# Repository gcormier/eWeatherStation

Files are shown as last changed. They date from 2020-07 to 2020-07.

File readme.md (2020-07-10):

# eWeatherstation
eWeatherstation is a simple weather station with a twist

1. It has an onboard temperature/humidity sensor
2. It can receive RF signals from nearby sensors such as the AcuRite 06002RM to display the actual outdoor temperature

It is powered by an ESP32, and has support for a LiPo battery and charging circuitry via Micro USB.

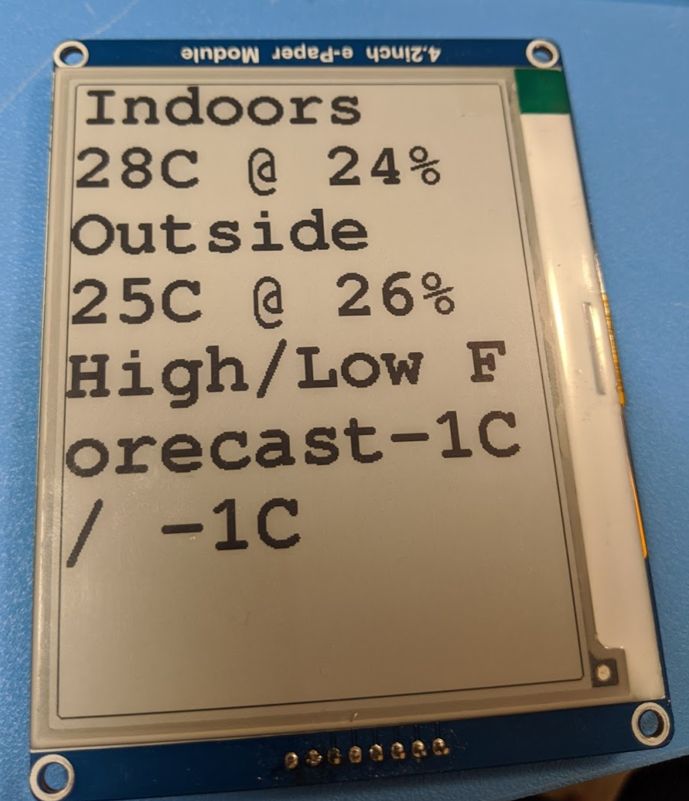
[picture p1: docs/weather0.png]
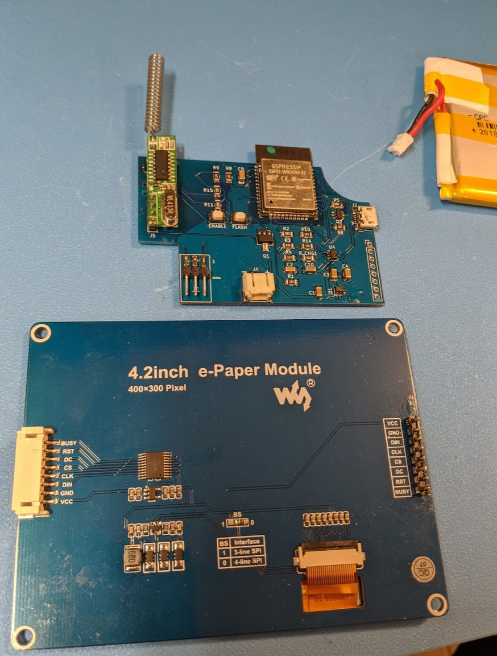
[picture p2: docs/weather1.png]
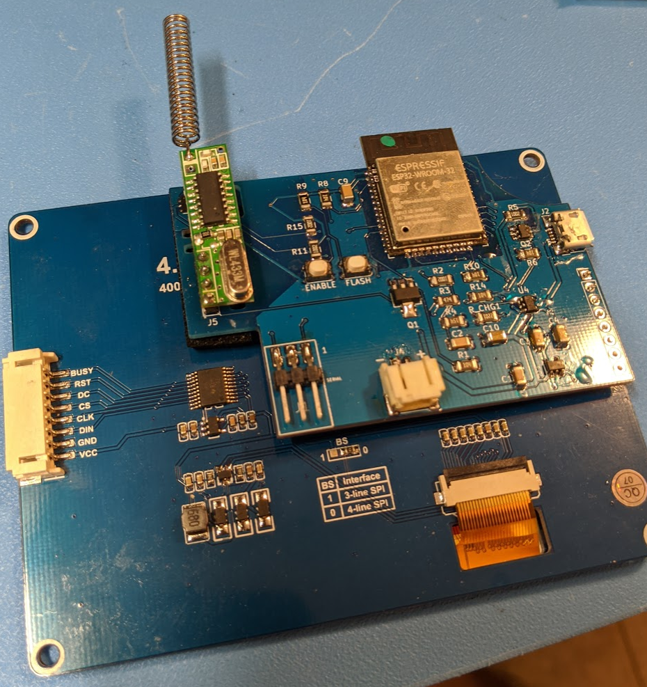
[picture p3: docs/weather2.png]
  

## Todo list
- [ ] 3D-Printed Housing
- [ ] Make UI look good
- [ ] Hardware revision to use esp32buddy programmer

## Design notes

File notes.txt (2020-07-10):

- Target 3v3, so 1S lipo
- Integrated charger, mcu detects low voltage
- No protection for battery+programming at the same time

https://download.mikroe.com/documents/add-on-boards/click/eink/eink-click-schematic-v101.pdf

- ESP32 in deep sleep - 2.8uA
- Around 45mA when in use (no wifi)
- takes about 140ms to wake up from deep sleep with an interrupt

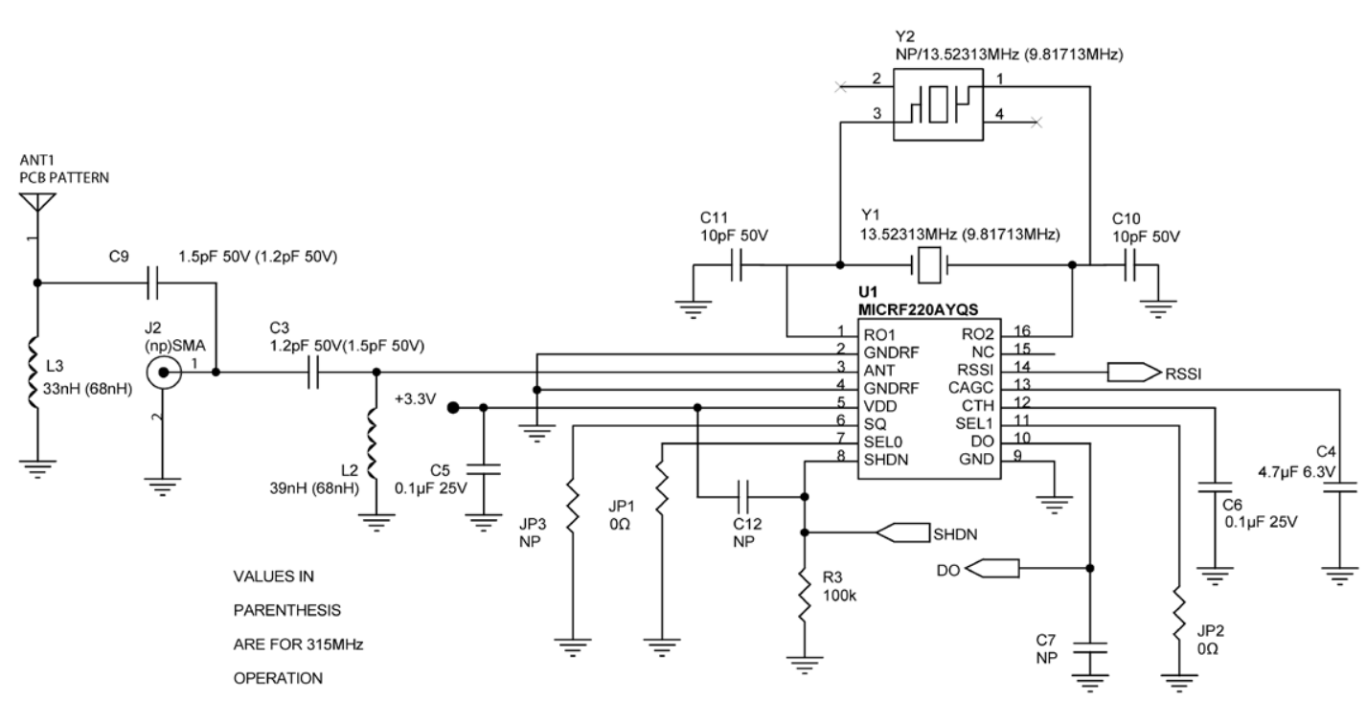
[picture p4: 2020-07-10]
pcb/MICRF220 Reference Schematic.png

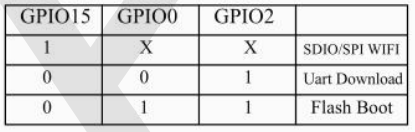
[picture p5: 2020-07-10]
pcb/8266 boot.png

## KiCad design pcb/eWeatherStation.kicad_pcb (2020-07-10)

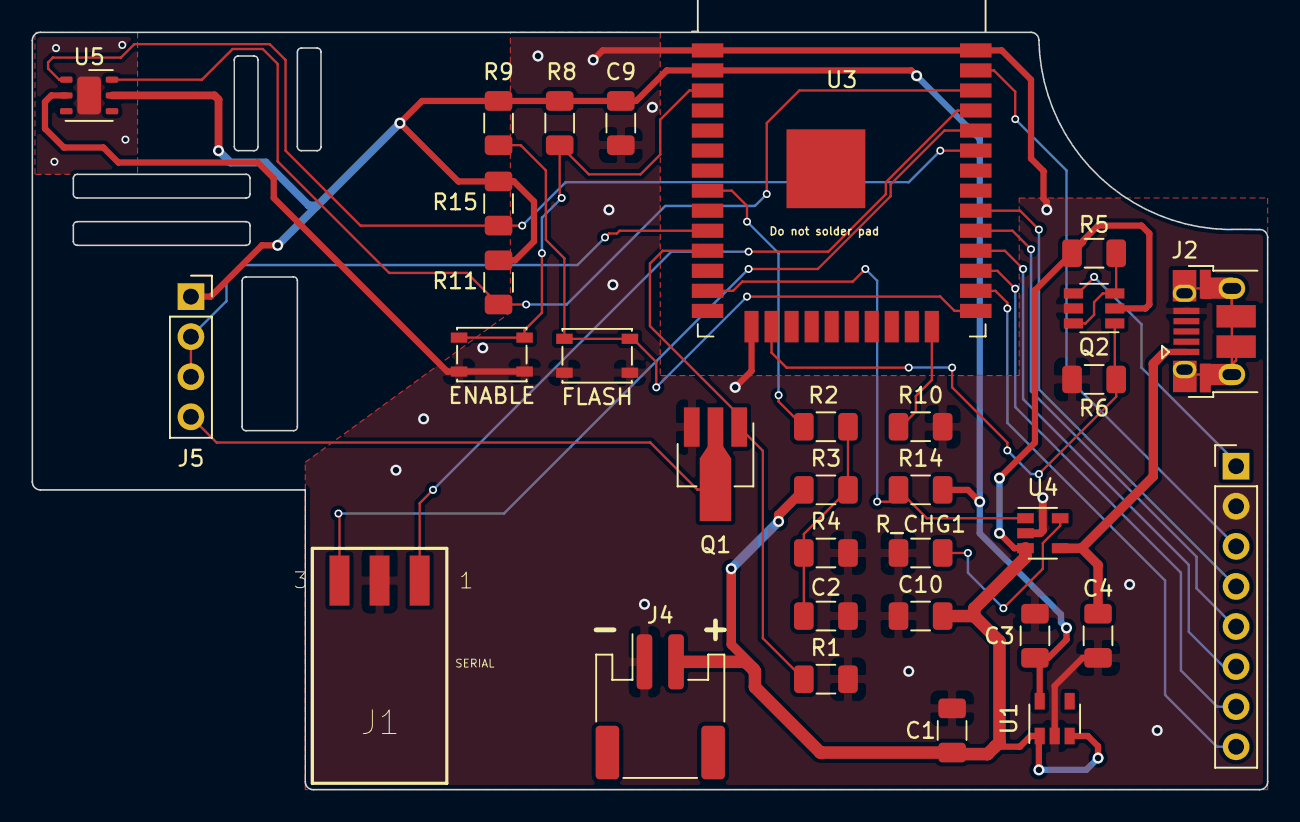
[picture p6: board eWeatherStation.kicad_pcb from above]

Board: 2 copper layers, 78.3 x 48.0 mm, 32 parts (0 on the bottom side), 27 nets.

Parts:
C1, C3: 1uF; C_1206_3216Metric
C2: 0.1uF; C_1206_3216Metric
C4, C10: 4.7uF; C_1206_3216Metric
C9: 10uF; C_1206_3216Metric
J1: SERIAL; SAMTEC-TSM-103-01-X-SH
J2: USB_B_Micro; USB_Micro-B_Amphenol_10103594-0001LF_Horizontal
J3: CASTELLATION; PinHeader_1x08_P2.54mm_Vertical
J4: 1S_BATTERY; JST_PH_S2B-PH-SM4-TB_1x02-1MP_P2.00mm_Horizontal
J5: RECEIVER; PinSocket_1x04_P2.54mm_Vertical
Q1: ZXMN3A01Z; SOT-89-3_Handsoldering
Q2: DMC2053UVT; TSOT-23-6
R1, R6, R8, R9, R10, R14: 100k; R_1206_3216Metric
R2, R5, R11, R15: 10k; R_1206_3216Metric
R3: 470k; R_1206_3216Metric
R4: 150k; R_1206_3216Metric
R_CHG1: 2k2; R_1206_3216Metric
SW1: ENABLE; SW_SPST_PTS810
SW2: FLASH; SW_SPST_PTS810
U1: TLV75533PDBV; SOT-23-5
U3: ESP32-WROOM-32D; ESP32-WROOM-32
U4: MCP73831-2-OT; SOT-23-5
U5: Si7021-A20; DFN-6-1EP_3x3mm_P1mm_EP1.5x2.4mm

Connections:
+3V3: C3.1, C9.2, J5.1, R8.2, R9.2, R11.1, R14.2, R15.1, U1.5, U3.2, U5.5
+BATT: C1.2, C10.2, J4.2, Q2.2, R3.2, R5.1, U1.1, U1.3, U4.3
/ADC_BATT: R2.2, U3.8
/CHG_STAT: R14.1, U3.13, U4.1
/DISPLAY_ENABLE: Q2.1, R6.1, U3.16
/RADIO: J5.2, J5.3, U3.10
/RADIO_ENABLE: Q1.1, R1.1, U3.11
/RXD: J1.3, U3.34
/SCL: R11.2, U3.36, U5.6
/SDA: R15.2, U3.33, U5.1
/TXD: J1.1, U3.35
/eBUSY: J3.8, U3.26
/eCLK: J3.4, U3.30
/eCS: J3.5, U3.29
/eDC: J3.6, U3.28
/eDIN: J3.3, U3.37
/eRST: J3.7, U3.27
GND: C1.1, C2.2, C3.2, C4.1, C9.1, C10.1, J1.2, J2.5, J3.2, J4.1, Q1.3, Q2.5, R1.2, R4.2, R6.2, R10.2, R_CHG1.1, SW1.2, SW2.2, U1.2, U3.1, U3.15, U3.38, U4.2, U5.2
unnamed: C2.1, R2.1, R3.1, R4.1
unnamed: J3.1, Q2.4
unnamed: J5.4, Q1.2
unnamed: Q2.3, Q2.6, R5.2
unnamed: R8.1, SW1.1, U3.3
unnamed: R9.1, SW2.1, U3.25
unnamed: R10.1, U3.24
unnamed: R_CHG1.2, U4.5
VBUS: C4.2, J2.1, U4.4

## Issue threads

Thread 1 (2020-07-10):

Help finishing software

gcormier, 2020-07-10:
Need some motivation to drive this home. Is anyone willing to finish off the code to look a bit better?

- [ ] Horizontal aspect ratio
- [ ] Pull weather forecast
- [ ] Make GUI look good

I'm willing to send off the hardware to get this done. I'd send a fully assembled PCB. You would need your own Waveshare e-ink display, Acurite sensor, and the tools and knowledge to program it. (It'd be great to have some sort of history/indication of your ability to do so)

(Battery is also up to you, but it can also be run off USB)

rruggiero, 2020-07-17:
Hi,

I am willing to help you with the design and prototyping of any 3d printed case you care thinking about.  Is it intended for indoor or out door use, or maybe both ?

As for the UI, what did you have in mind for that ?

Cheers,

Rick (Queensland, Australia)

gcormier, 2020-07-17:
Awesome! I think the case could be very simple, it merely needs to provide access to the USB port for charging. It is for interior use.

GUI also simple is fine. If it's just showing the various temperatures, a simple breakdown. If it's showing weather forecast, looks like there are already many many weatherstations that do that, so it could be just reworking those to be a bit smaller. https://learn.adafruit.com/epaper-weather-station

Thinking more about it,  I already have many devices that show me weather forecasts... Ecobee, phones, google speakers.. I've always cared more about what it actually is outside my house and not at the airport :)

In which case, the UI could simply be nicely formatted indoor and outdoor temps. Perhaps, depending on the season, the forecasted extremes (low/high) for the day? I am quite open to suggestion.

gcormier, 2020-07-17:
Oh wow, this one looks like it already has some space in the bottom for an internal sensor - and room to the right easily for an external one.

https://github.com/andrei7c4/weatherdisplay

gcormier, 2020-07-29:
Hey Rick, were you still interested?

rruggiero, 2020-07-30:
H Greg,

I think you were looking for someone to look at the interface and case, is the correct.  Well, I would like to offer any assistance you may need on this project.

Kindest regards,

Rick Ruggiero

e: rick.ruggiero@gmail.com <mailto:rick.ruggiero@gmail.com>

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

gcormier, 2020-07-30:
Yup that sounds good! If you want to send me an email with your address I
can send you the board in a week or two to start playing. As mentioned
you'll need your own e-ink display and programming tools.

On Wed, Jul 29, 2020 at 11:55 PM Rick Ruggiero <notifications@github.com>
wrote:

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

Closed 2023-06-22.

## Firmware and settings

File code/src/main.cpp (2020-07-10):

#include <Arduino.h>
#include <EPD_WaveShare.h>     // Copyright (c) 2017 by Daniel Eichhorn https://github.com/ThingPulse/minigrafx
#include "EPD_WaveShare_42.h"  // Copyright (c) 2017 by Daniel Eichhorn https://github.com/ThingPulse/minigrafx
#include <MiniGrafx.h>         // Copyright (c) 2017 by Daniel Eichhorn https://github.com/ThingPulse/minigrafx
#include "DisplayDriver.h"     // Copyright (c) 2017 by Daniel Eichhorn https://github.com/ThingPulse/minigrafx
#include "ArialRounded.h"      // Copyright (c) 2017 by Daniel Eichhorn https://github.com/ThingPulse/minigrafx
#include "owm_credentials2.h"  // See 'owm_credentials' tab and enter your OWM API key and set the Wifi SSID and PASSWORD
#include <ArduinoJson.h>       // https://github.com/bblanchon/ArduinoJson NOTE: *** MUST BE Version-6 or above ***

#include <Adafruit_Si7021.h>
#include <WiFi.h>
#include <ESPmDNS.h>
#include <ArduinoOTA.h>
#include <WebServer.h>
#include <SPIFFS.h>

#include "accurite.h"
#include <WeatherArtFunctions.h>

/********Weather headers********/

WiFiClient client; // wifi client object
/*******************/

#define SENSOR_ID_FILTER    0x1023

const char* ssid = "aaaa";
const char* password = "aaaa";

RTC_DATA_ATTR unsigned long currentMillis = 0;
RTC_DATA_ATTR unsigned long lastLocalMillis = 0, lastRemoteMillis = 0, lastNetMillis = 0;
unsigned long waitingRemoteWeather = 0;

const char HelloWorld[] = "Hello World!";
const char HelloArduino[] = "Hello Arduino!";

#define HOST_NAME "eWeather"

// Added to the battery reading for fine tuning
#define BATTERY_OFFSET  0.18f

// How long to sleep between reading measurements
#define INTERVAL_SLEEP      15
#define INTERVAL_LOCAL      60
#define INTERVAL_REMOTE     120
#define INTERVAL_NET        30
#define INTERVAL_REMOTE_TIMEOUT 45    // How many seconds until we timeout waiting for the remote sensor to transmit

#define PIN_PAPER_BUSY	4
#define PIN_PAPER_RST		16
#define PIN_PAPER_DC		17
#define PIN_PAPER_CLK		18
#define PIN_PAPER_CS		5
#define PIN_PAPER_DIN		23

#define PIN_CHGSTAT			14
#define PIN_ADC_BATT		32

#define PIN_LED1        13
#define PIN_LED2        15
#define PIN_BUZZER      27

#define PIN_RADIO       25
#define PIN_RADIO_EN    26

/* RF SECTION*/
// sync states
#define RESET     0   // no sync yet
#define INSYNC    1   // sync pulses detected 
#define SYNCDONE  2   // complete sync header received 

#define MAXBITS      55

// pulse timings
// SYNC
#define SYNC_HI      700
#define SYNC_LO      550

// HIGH == 1
#define LONG_HI      475
#define LONG_LO      330

// SHORT == 0
#define SHORT_HI     275
#define SHORT_LO     150

#define RESETTIME    2000  // Probably can go to 2000 once debugging complete

volatile unsigned int    pulsecnt = 0;
volatile unsigned long   risets = 0;     // track rising edge time
volatile unsigned int    syncpulses = 0; // track sync pulses
volatile byte            state = RESET;
volatile byte            buf[7] = { 0,0,0,0,0,0,0 };  // msg frame buffer
volatile bool            haveReading = false;            // have valid reading
/* END RF SECTION*/

bool screenUpdate = false;


byte currentTemp;
byte currentHumidity;
bool batteryStatus;



Adafruit_Si7021 sensor = Adafruit_Si7021();

RTC_DATA_ATTR float localTemp, localHumidity;
RTC_DATA_ATTR float remoteTemp, remoteHumidity;
RTC_DATA_ATTR bool remoteBatteryLow, localBatteryLow;

void updateLocalWeather();
void updateNetWeather();
void updateRemoteWeather();
void fallingPulseHandler();
void updateScreen();
void sleepyTime();
void startWeather();
int StartWiFi();
void SetupTime();
void StopWiFi();
void Draw_Heading_Section();
void Display_Weather();

void setup()
{
  pinMode(19, INPUT);   // Hack until PCB revision 3

  pinMode(PIN_RADIO_EN, OUTPUT);
  pinMode(PIN_RADIO, INPUT);
  pinMode(PIN_LED1, OUTPUT);
  pinMode(PIN_LED2, OUTPUT);
  pinMode(PIN_ADC_BATT, INPUT);
  pinMode(PIN_CHGSTAT, INPUT);

  digitalWrite(PIN_RADIO_EN, LOW);
  digitalWrite(PIN_LED1, LOW);
  digitalWrite(PIN_LED2, LOW);

  Serial.begin(115200);
  delay(25);

  if (currentMillis == 0) // First time starting up
  {
    updateLocalWeather();
    updateNetWeather();
    updateRemoteWeather();
  }

}

// 75uA during deep sleep without screen
// 210uA during deep sleep with screen
// 35mA when checking remote
// 25mA when checking local

// Do we have to do anything?
void checkForActivity()
{
  // TODO: BUG HERE, need to up millis by factor of 10?!?!?!
  currentMillis += millis() * 10UL;
  currentMillis += INTERVAL_SLEEP * 1000UL; // Need to add all the time we slept too

  Serial.println(currentMillis);


  if (currentMillis - lastLocalMillis > (INTERVAL_LOCAL * 1000UL))
  {
    updateLocalWeather();
    screenUpdate = true;
  }

  if (currentMillis - lastRemoteMillis > (INTERVAL_REMOTE * 1000UL))
  {
    updateRemoteWeather();
  }

  if (currentMillis - lastNetMillis > (INTERVAL_NET * 1000UL))
  {
    updateNetWeather();
    screenUpdate = true;
  }
}


void enableRadio()
{
  digitalWrite(PIN_RADIO_EN, HIGH);
  attachInterrupt(PIN_RADIO, fallingPulseHandler, CHANGE);
}

void loop()
{


  while (waitingRemoteWeather > 0)
  {
    unsigned int sensorID;

    if (millis() - waitingRemoteWeather > (INTERVAL_REMOTE_TIMEOUT * 1000UL)) // Timed out waiting for something
    {
      waitingRemoteWeather = 0;
      lastRemoteMillis = currentMillis + (millis() * 10);
    }

    if (haveReading)
    {
      noInterrupts();
      if (acurite_crc(buf, sizeof(buf)))
      {
        if (getMessageType(buf[2]) == 4)
        {
          remoteTemp = getTempC(buf[4], buf[5]);
          remoteHumidity = getHumidity(buf[3]);
          remoteBatteryLow = getLowBatteryStatus(buf[2]);
          sensorID = getSensorID(buf[0], buf[1]);
        }
      }

      haveReading = false;
      if (sensorID == SENSOR_ID_FILTER)
      {
        screenUpdate = true;
        waitingRemoteWeather = 0;
        lastRemoteMillis = currentMillis + (millis() * 10);
        digitalWrite(PIN_RADIO_EN, LOW);
      }
      interrupts();
    }
  }

  checkForActivity();

  if (screenUpdate)
  {
    screenUpdate = false;
    updateScreen();
  }

  // Check if we can go to sleep
  if (waitingRemoteWeather == 0)
  {
    sleepyTime();
  }

}

void sleepyTime()
{
  esp_sleep_enable_timer_wakeup(INTERVAL_SLEEP * 1000000);
  esp_deep_sleep_start();
}

// Update local weather
void updateLocalWeather()
{
  Serial.println("Update local...");

  if (!sensor.begin())
    return;

  localTemp = sensor.readTemperature();
  localHumidity = sensor.readHumidity();
  lastLocalMillis = currentMillis;
  Serial.println(localTemp);
  Serial.println(localHumidity);
}

// Update remote weather
void updateRemoteWeather()
{
  Serial.println("Update remote...");

  waitingRemoteWeather = millis();
  enableRadio();
}

// Update weather from the internet
void updateNetWeather()
{
  Serial.println("Update net...");
  lastNetMillis = currentMillis;
  startWeather();
}


// Update e-ink display with new weather values
void updateScreen()
{
  Serial.println("updateScreen()");

}

void enableWifi()
{
  if (WiFi.isConnected())
    return;

  WiFi.mode(WIFI_STA);
  WiFi.begin(ssid, password);
  while (WiFi.waitForConnectResult() != WL_CONNECTED)
  {
    Serial.println("Connection Failed! Rebooting...");
    delay(5000);
    ESP.restart();
  }
}

void setupOTA()
{
  Serial.println("Setup OTA...");
  enableWifi();

  if (MDNS.begin("esp32"))
  {
    Serial.println("MDNS responder started");
  }

  ArduinoOTA.setHostname("esp32-weather");

  ArduinoOTA
    .onStart([]() {

    String type;
    if (ArduinoOTA.getCommand() == U_FLASH)
      type = "sketch";
    else // U_SPIFFS
      type = "filesystem";

    // NOTE: if updating SPIFFS this would be the place to unmount SPIFFS using SPIFFS.end()
    Serial.println("Start updating " + type);

    // Detach interrupt so it doesn't interrupt the OTA flashing.
    detachInterrupt(PIN_RADIO);
  })
    .onEnd([]() {
    Serial.println("\nEnd");
  })
    .onProgress([](unsigned int progress, unsigned int total) {
    Serial.printf("Progress: %u%%\r\n", (progress / (total / 100)));
  })
    .onError([](ota_error_t error) {
    Serial.printf("Error[%u]: ", error);
    if (error == OTA_AUTH_ERROR) Serial.println("Auth Failed");
    else if (error == OTA_BEGIN_ERROR) Serial.println("Begin Failed");
    else if (error == OTA_CONNECT_ERROR) Serial.println("Connect Failed");
    else if (error == OTA_RECEIVE_ERROR) Serial.println("Receive Failed");
    else if (error == OTA_END_ERROR) Serial.println("End Failed");
  });

  Serial.println("Ready");
  Serial.print("IP address: ");
  Serial.println(WiFi.localIP());

  ArduinoOTA.begin();
}

void setupPaper()
{
  Serial.println("Setup e-ink...");

}


void fallingPulseHandler()
{
  unsigned long timestamp = micros();
  if (digitalRead(PIN_RADIO) == HIGH)
  {
    // going high, start timing
    if (timestamp - risets > RESETTIME)
    {
      // detect reset condition
      state = RESET;
      syncpulses = 0;
      pulsecnt = 0;
    }
    risets = timestamp;
    return;
  }

  // going low
  unsigned long duration = timestamp - risets;

  if (state == RESET || state == INSYNC)
  {
    // looking for sync pulses
    if ((SYNC_LO) < duration && duration < (SYNC_HI))
    {
      // start counting sync pulses
      state = INSYNC;
      syncpulses++;
      if (syncpulses > 3)
      {
        // found complete sync header
        state = SYNCDONE;
        syncpulses = 0;
        pulsecnt = 0;
      }
      return;

    }
    else
    {
      // not interested, reset  
      syncpulses = 0;
      pulsecnt = 0;
      state = RESET;

      return;
    }
  }
  else
  {
    // SYNCDONE, now look for message 
    // detect if finished here
    if (pulsecnt > MAXBITS)
    {
      state = RESET;
      pulsecnt = 0;
      haveReading = true;
      return;
    }
    // stuff buffer with message
    byte bytepos = pulsecnt / 8;
    byte bitpos = 7 - (pulsecnt % 8); // reverse bitorder
    if (LONG_LO < duration && duration < LONG_HI)
    {
      bitSet(buf[bytepos], bitpos);
      pulsecnt++;
    }
    else if (SHORT_LO < duration && duration < SHORT_HI)
    {
      bitClear(buf[bytepos], bitpos);
      pulsecnt++;
    }
  }

}

float getBatteryVoltage()
{
  analogReadResolution(12);
  analogSetAttenuation(ADC_0db);
  analogSetWidth(12);
  adcAttachPin(PIN_ADC_BATT);

  uint16_t val = analogRead(PIN_ADC_BATT);
  float conv = val / 4096.0;

  return ((conv * 620) / 150) + BATTERY_OFFSET;
}




/* ****
  Weather code below
  */




void startWeather()
{
  StartWiFi();
  SetupTime();
  bool Received_WxData_OK = false;
  Received_WxData_OK = (obtain_wx_data("weather") && obtain_wx_data("forecast"));
  // Now only refresh the screen if all the data was received OK, otherwise wait until the next timed check otherwise wait until the next timed check
  if (Received_WxData_OK)
  {
    StopWiFi(); // Reduces power consumption
    gfx.init();
    gfx.setRotation(0);
    gfx.setColor(EPD_BLACK);
    gfx.fillBuffer(EPD_WHITE);
    gfx.setTextAlignment(TEXT_ALIGN_LEFT);
    Display_Weather();
    DrawBattery(SCREEN_WIDTH - 65, 0);
    gfx.commit();
    delay(2000);
  }
}

void Display_Weather()
{
  Draw_Heading_Section();             // Top line of the display
  Draw_Main_Weather_Section(170, 70); // Centre section of display for Location, temperature, Weather report, current Wx Symbol and wind direction
  //Draw_Forecast_Section(230, 18);     // 3hr forecast boxes
  Draw_Astronomy_Section(230, 20);    // Astronomy section Sun rise/set, Moon phase and Moon icon

  gfx.drawString(10, 200, String(remoteTemp));
  gfx.drawString(10, 230, String(remoteHumidity));

  gfx.drawString(10, 260, String(localTemp));
  gfx.drawString(10, 290, String(localHumidity));


}

void Draw_Heading_Section()
{
  gfx.setFont(ArialRoundedMTBold_14);
  gfx.setTextAlignment(TEXT_ALIGN_CENTER);
  gfx.drawString(SCREEN_WIDTH / 2, -2, City);
  gfx.setFont(ArialMT_Plain_10);
  gfx.setTextAlignment(TEXT_ALIGN_RIGHT);
  gfx.drawString(SCREEN_WIDTH - 3, 0, Day_time_str);
  gfx.setTextAlignment(TEXT_ALIGN_LEFT);
  gfx.drawString(5, 0, time_str);
  gfx.drawLine(0, 15, SCREEN_WIDTH, 15);
}

void Draw_Main_Weather_Section(int x, int y)
{
  DisplayWXicon(x + 5, y - 5, WxConditions[0].Icon, LargeIcon);
  gfx.setFont(ArialRoundedMTBold_14);
  DrawPressureTrend(x, y + 50, WxConditions[0].Pressure, WxConditions[0].Trend);
  gfx.setTextAlignment(TEXT_ALIGN_CENTER);
  Draw_Rain(x - 100, y + 35);
  gfx.setFont(ArialMT_Plain_24);
  gfx.setTextAlignment(TEXT_ALIGN_LEFT);
  String Wx_Description = WxConditions[0].Main0;
  if (WxConditions[0].Forecast0 != "")
  {
    Wx_Description += " (" + WxConditions[0].Forecast0;
    if (WxConditions[0].Forecast1 != "" && WxConditions[0].Forecast1 != WxConditions[0].Forecast2) Wx_Description += " & " + WxConditions[0].Forecast1 + ")";
    else Wx_Description += ")";
  }
  gfx.drawString(x - 170, y + 70, TitleCase(Wx_Description));
  Draw_Main_Wx(x - 98, y - 1);
  gfx.drawLine(0, y + 68, SCREEN_WIDTH, y + 68);
}

String TitleCase(String text)
{
  if (text.length() > 0)
  {
    String temp_text = text.substring(0, 1);
    temp_text.toUpperCase();
    return temp_text + text.substring(1); // Title-case the string
  }
  return "";
}

void Draw_Forecast_Section(int x, int y)
{
  gfx.setFont(ArialMT_Plain_10);
  Draw_Forecast_Weather(x, y, 0);
  Draw_Forecast_Weather(x + 56, y, 1);
  Draw_Forecast_Weather(x + 112, y, 2);
  //       (x,y,width,height,MinValue, MaxValue, Title, Data Array, AutoScale, ChartMode)
  for (int r = 1; r <= max_readings; r++)
  {
    if (Units == "I") pressure_readings[r] = WxForecast[r].Pressure * 0.02953;
    else              pressure_readings[r] = WxForecast[r].Pressure;
    temperature_readings[r] = WxForecast[r].Temperature;
    if (Units == "I") rain_readings[r] = WxForecast[r].Rainfall * 0.0393701;
    else              rain_readings[r] = WxForecast[r].Rainfall;
  }
  gfx.drawLine(0, y + 173, SCREEN_WIDTH, y + 173);
  gfx.setTextAlignment(TEXT_ALIGN_CENTER);
  gfx.setFont(ArialRoundedMTBold_14);
  gfx.drawString(x - 40, y + 173, "3-Day Forecast Values");
  gfx.setTextAlignment(TEXT_ALIGN_LEFT);
  gfx.setFont(ArialMT_Plain_10);
  DrawGraph(SCREEN_WIDTH / 400 * 30, SCREEN_HEIGHT / 300 * 222, SCREEN_WIDTH / 400 * 100, SCREEN_HEIGHT / 300 * 60, 900, 1050, "Pressure", pressure_readings, max_readings, autoscale_on, barchart_off);
  DrawGraph(SCREEN_WIDTH / 400 * 158, SCREEN_HEIGHT / 300 * 222, SCREEN_WIDTH / 400 * 100, SCREEN_HEIGHT / 300 * 60, 10, 30, "Temperature", temperature_readings, max_readings, autoscale_on, barchart_off);
  DrawGraph(SCREEN_WIDTH / 400 * 288, SCREEN_HEIGHT / 300 * 222, SCREEN_WIDTH / 400 * 100, SCREEN_HEIGHT / 300 * 60, 0, 30, "Rainfall", rain_readings, max_readings, autoscale_on, barchart_on);
}

void Draw_Forecast_Weather(int x, int y, int index)
{
  gfx.setFont(ArialMT_Plain_10);
  gfx.setColor(EPD_BLACK); // Sometimes gets set to WHITE, so change back
  gfx.drawRect(x, y, 55, 65);
  gfx.drawLine(x + 1, y + 13, x + 55, y + 13);
  DisplayWXicon(x + 28, y + 35, WxForecast[index].Icon, SmallIcon);
  gfx.setTextAlignment(TEXT_ALIGN_CENTER);
  gfx.setFont(ArialMT_Plain_10);
  gfx.drawString(x + 28, y, String(WxForecast[index].Period.substring(11, 16)));
  gfx.drawString(x + 28, y + 50, String(WxForecast[index].High, 0) + "� / " + String(WxForecast[index].Low, 0) + "�");
}

void Draw_Main_Wx(int x, int y)
{
  DrawWind(x, y, WxConditions[0].Winddir, WxConditions[0].Windspeed);
  gfx.setTextAlignment(TEXT_ALIGN_CENTER);
  gfx.setFont(ArialRoundedMTBold_14);
  gfx.drawString(x, y - 28, String(WxConditions[0].High, 0) + "� | " + String(WxConditions[0].Low, 0) + "�"); // Show forecast high and Low
  gfx.setFont(ArialMT_Plain_24);
  gfx.drawString(x - 5, y - 10, String(WxConditions[0].Temperature, 1) + "�"); // Show current Temperature
  gfx.setFont(ArialRoundedMTBold_14);
  gfx.setTextAlignment(TEXT_ALIGN_LEFT);
  gfx.drawString(x + String(WxConditions[0].Temperature, 1).length() * 11 / 2, y - 9, Units == "M" ? "C" : "F"); // Add in smaller Temperature unit
  gfx.setFont(ArialRoundedMTBold_14);
  gfx.setTextAlignment(TEXT_ALIGN_LEFT);
}

void DrawWind(int x, int y, float angle, float windspeed)
{
  int Cradius = 44;
  //float dx = Cradius * cos((angle - 90) * PI / 180) + x; // calculate X position
  //float dy = Cradius * sin((angle - 90) * PI / 180) + y; // calculate Y position
  arrow(x, y, Cradius - 3, angle, 15, 15); // Show wind direction on outer circle
  gfx.drawCircle(x, y, Cradius + 2);
  gfx.drawCircle(x, y, Cradius + 3);
  gfx.setTextAlignment(TEXT_ALIGN_CENTER);
  gfx.setFont(ArialRoundedMTBold_14);
  gfx.drawString(x, y + Cradius - 25, WindDegToDirection(angle));
  gfx.setFont(ArialMT_Plain_10);
  gfx.drawString(x - Cradius + 3, y - Cradius - 6, String(windspeed, 1) + (Units == "M" ? " m/s" : " mph"));
  gfx.setTextAlignment(TEXT_ALIGN_LEFT);
}

String WindDegToDirection(float winddirection)
{
  if (winddirection >= 348.75 || winddirection < 11.25)  return "N";
  if (winddirection >= 11.25 && winddirection < 33.75)  return "NNE";
  if (winddirection >= 33.75 && winddirection < 56.25)  return "NE";
  if (winddirection >= 56.25 && winddirection < 78.75)  return "ENE";
  if (winddirection >= 78.75 && winddirection < 101.25) return "E";
  if (winddirection >= 101.25 && winddirection < 123.75) return "ESE";
  if (winddirection >= 123.75 && winddirection < 146.25) return "SE";
  if (winddirection >= 146.25 && winddirection < 168.75) return "SSE";
  if (winddirection >= 168.75 && winddirection < 191.25) return "S";
  if (winddirection >= 191.25 && winddirection < 213.75) return "SSW";
  if (winddirection >= 213.75 && winddirection < 236.25) return "SW";
  if (winddirection >= 236.25 && winddirection < 258.75) return "WSW";
  if (winddirection >= 258.75 && winddirection < 281.25) return "W";
  if (winddirection >= 281.25 && winddirection < 303.75) return "WNW";
  if (winddirection >= 303.75 && winddirection < 326.25) return "NW";
  if (winddirection >= 326.25 && winddirection < 348.75) return "NNW";
  return "?";
}


int JulianDate(int d, int m, int y)
{
  int mm, yy, k1, k2, k3, j;
  yy = y - (int)((12 - m) / 10);
  mm = m + 9;
  if (mm >= 12) mm = mm - 12;
  k1 = (int)(365.25 * (yy + 4712));
  k2 = (int)(30.6001 * mm + 0.5);
  k3 = (int)((int)((yy / 100) + 49) * 0.75) - 38;
  // 'j' for dates in Julian calendar:
  j = k1 + k2 + d + 59 + 1;
  if (j > 2299160) j = j - k3; // 'j' is the Julian date at 12h UT (Universal Time) For Gregorian calendar:
  return j;
}

String MoonPhase(int d, int m, int y, String hemisphere)
{
  int c, e;
  double jd;
  int b;
  if (m < 3)
  {
    y--;
    m += 12;
  }
  ++m;
  c = 365.25 * y;
  e = 30.6 * m;
  jd = c + e + d - 694039.09;           /* jd is total days elapsed */
  jd /= 29.53059;                        /* divide by the moon cycle (29.53 days) */
  b = jd;                              /* int(jd) -> b, take integer part of jd */
  jd -= b;                               /* subtract integer part to leave fractional part of original jd */
  b = jd * 8 + 0.5;                    /* scale fraction from 0-8 and round by adding 0.5 */
  b = b & 7;                           /* 0 and 8 are the same phase so modulo 8 for 0 */
  if (hemisphere == "south") b = 7 - b;
  if (b == 0) return "New";              // New; 0% illuminated
  if (b == 1) return "Waxing crescent";  // Waxing crescent; 25% illuminated
  if (b == 2) return "First quarter";    // First quarter; 50% illuminated
  if (b == 3) return "Waxing gibbous";   // Waxing gibbous; 75% illuminated
  if (b == 4) return "Full";             // Full; 100% illuminated
  if (b == 5) return "Waning gibbous";   // Waning gibbous; 75% illuminated
  if (b == 6) return "Third quarter";    // Last quarter; 50% illuminated
  if (b == 7) return "Waning crescent";  // Waning crescent; 25% illuminated
  return "";
}

void DrawCircle(int x, int y, int Cstart, int Cend, int Cradius, int Coffset_radius, int Coffset)
{
  gfx.setColor(EPD_BLACK);
  float dx, dy;
  for (int i = Cstart; i < Cend; i++)
  {
    dx = (Cradius + Coffset_radius) * cos((i - 90) * PI / 180) + x + Coffset / 2; // calculate X position
    dy = (Cradius + Coffset_radius) * sin((i - 90) * PI / 180) + y; // calculate Y position
    gfx.setPixel(dx, dy);
  }
}

void arrow(int x, int y, int asize, float aangle, int pwidth, int plength)
{
  float dx = (asize - 10) * cos((aangle - 90) * PI / 180) + x; // calculate X position
  float dy = (asize - 10) * sin((aangle - 90) * PI / 180) + y; // calculate Y position
  float x1 = 0;         float y1 = plength;
  float x2 = pwidth / 2;  float y2 = pwidth / 2;
  float x3 = -pwidth / 2; float y3 = pwidth / 2;
  float angle = aangle * PI / 180 - 135;
  float xx1 = x1 * cos(angle) - y1 * sin(angle) + dx;
  float yy1 = y1 * cos(angle) + x1 * sin(angle) + dy;
  float xx2 = x2 * cos(angle) - y2 * sin(angle) + dx;
  float yy2 = y2 * cos(angle) + x2 * sin(angle) + dy;
  float xx3 = x3 * cos(angle) - y3 * sin(angle) + dx;
  float yy3 = y3 * cos(angle) + x3 * sin(angle) + dy;
  gfx.fillTriangle(xx1, yy1, xx3, yy3, xx2, yy2);
}
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

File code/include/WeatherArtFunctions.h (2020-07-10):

#pragma once

#include <WeatherDeclarations.h>

void addcloud(int x, int y, int scale, int linesize);
String ConvertUnixTime(int unix_time);
void addrain(int x, int y, int scale);
void addsnow(int x, int y, int scale);
void addtstorm(int x, int y, int scale);
void addsun(int x, int y, int scale);
void addfog(int x, int y, int scale, int linesize);
void MostlyCloudy(int x, int y, bool LargeSize, String IconName);
void MostlySunny(int x, int y, bool LargeSize, String IconName);
void Rain(int x, int y, bool LargeSize, String IconName);
void Cloudy(int x, int y, bool LargeSize, String IconName);
void Sunny(int x, int y, bool LargeSize, String IconName);
void ExpectRain(int x, int y, bool LargeSize, String IconName);
void ChanceRain(int x, int y, bool LargeSize, String IconName);
void Tstorms(int x, int y, bool LargeSize, String IconName);
void Snow(int x, int y, bool LargeSize, String IconName);
void Fog(int x, int y, bool LargeSize, String IconName);
void Haze(int x, int y, bool LargeSize, String IconName);
void addmoon(int x, int y, int scale);


String ConvertUnixTime(int unix_time)
{
  struct tm *now_tm;
  int hour, min, second, day, month, year, wday;
  // timeval tv = {unix_time,0};
  time_t tm = unix_time;
  now_tm = localtime(&tm);
  hour = now_tm->tm_hour;
  min = now_tm->tm_min;
  second = now_tm->tm_sec;
  wday = now_tm->tm_wday;
  day = now_tm->tm_mday;
  month = now_tm->tm_mon + 1;
  year = 1900 + now_tm->tm_year; // To get just YY information
  MoonDay = day;
  MoonMonth = month;
  MoonYear = year;
  if (Units == "M")
  {
    time_str = (hour < 10 ? "0" + String(hour) : String(hour)) + ":" + (min < 10 ? "0" + String(min) : String(min)) + ":" + "  ";                     // HH:MM   05/07/17
    time_str += (day < 10 ? "0" + String(day) : String(day)) + "/" + (month < 10 ? "0" + String(month) : String(month)) + "/" + (year < 10 ? "0" + String(year) : String(year)); // HH:MM   05/07/17
  }
  else
  {
    String ampm = "am";
    if (hour > 11) ampm = "pm";
    hour = hour % 12; if (hour == 0) hour = 12;
    time_str = (hour % 12 < 10 ? "0" + String(hour % 12) : String(hour % 12)) + ":" + (min < 10 ? "0" + String(min) : String(min)) + ampm + " ";      // HH:MMam 07/05/17
    time_str += (month < 10 ? "0" + String(month) : String(month)) + "/" + (day < 10 ? "0" + String(day) : String(day)) + "/" + "/" + (year < 10 ? "0" + String(year) : String(year)); // HH:MMpm 07/05/17
  }
  // Returns either '21:12  ' or ' 09:12pm' depending on Units
  //Serial.println(time_str);
  return time_str;
}
// Symbols are drawn on a relative 10x10grid and 1 scale unit = 1 drawing unit
void addcloud(int x, int y, int scale, int linesize)
{
  //Draw cloud outer
  gfx.fillCircle(x - scale * 3, y, scale);                       // Left most circle
  gfx.fillCircle(x + scale * 3, y, scale);                       // Right most circle
  gfx.fillCircle(x - scale, y - scale, scale * 1.4);             // left middle upper circle
  gfx.fillCircle(x + scale * 1.5, y - scale * 1.3, scale * 1.75); // Right middle upper circle
  gfx.fillRect(x - scale * 3 - 1, y - scale, scale * 6, scale * 2 + 1); // Upper and lower lines
  //Clear cloud inner
  gfx.setColor(EPD_WHITE);
  gfx.fillCircle(x - scale * 3, y, scale - linesize);            // Clear left most circle
  gfx.fillCircle(x + scale * 3, y, scale - linesize);            // Clear right most circle
  gfx.fillCircle(x - scale, y - scale, scale * 1.4 - linesize);  // left middle upper circle
  gfx.fillCircle(x + scale * 1.5, y - scale * 1.3, scale * 1.75 - linesize); // Right middle upper circle
  gfx.fillRect(x - scale * 3 + 2, y - scale + linesize - 1, scale * 5.9, scale * 2 - linesize * 2 + 2); // Upper and lower lines
  gfx.setColor(EPD_BLACK);
}
void addrain(int x, int y, int scale)
{
  y = y + scale / 2;
  for (int i = 0; i < 6; i++)
  {
    gfx.drawLine(x - scale * 4 + scale * i * 1.3 + 0, y + scale * 1.9, x - scale * 3.5 + scale * i * 1.3 + 0, y + scale);
    if (scale != Small)
    {
      gfx.drawLine(x - scale * 4 + scale * i * 1.3 + 1, y + scale * 1.9, x - scale * 3.5 + scale * i * 1.3 + 1, y + scale);
      gfx.drawLine(x - scale * 4 + scale * i * 1.3 + 2, y + scale * 1.9, x - scale * 3.5 + scale * i * 1.3 + 2, y + scale);
    }
  }
}
void addsnow(int x, int y, int scale)
{
  int dxo, dyo, dxi, dyi;
  for (int flakes = 0; flakes < 5; flakes++)
  {
    for (int i = 0; i < 360; i = i + 45)
    {
      dxo = 0.5 * scale * cos((i - 90) * 3.14 / 180); dxi = dxo * 0.1;
      dyo = 0.5 * scale * sin((i - 90) * 3.14 / 180); dyi = dyo * 0.1;
      gfx.drawLine(dxo + x + 0 + flakes * 1.5 * scale - scale * 3, dyo + y + scale * 2, dxi + x + 0 + flakes * 1.5 * scale - scale * 3, dyi + y + scale * 2);
    }
  }
}
void addtstorm(int x, int y, int scale)
{
  y = y + scale / 2;
  for (int i = 0; i < 5; i++)
  {
    gfx.drawLine(x - scale * 4 + scale * i * 1.5 + 0, y + scale * 1.5, x - scale * 3.5 + scale * i * 1.5 + 0, y + scale);
    if (scale != Small)
    {
      gfx.drawLine(x - scale * 4 + scale * i * 1.5 + 1, y + scale * 1.5, x - scale * 3.5 + scale * i * 1.5 + 1, y + scale);
      gfx.drawLine(x - scale * 4 + scale * i * 1.5 + 2, y + scale * 1.5, x - scale * 3.5 + scale * i * 1.5 + 2, y + scale);
    }
    gfx.drawLine(x - scale * 4 + scale * i * 1.5, y + scale * 1.5 + 0, x - scale * 3 + scale * i * 1.5 + 0, y + scale * 1.5 + 0);
    if (scale != Small)
    {
      gfx.drawLine(x - scale * 4 + scale * i * 1.5, y + scale * 1.5 + 1, x - scale * 3 + scale * i * 1.5 + 0, y + scale * 1.5 + 1);
      gfx.drawLine(x - scale * 4 + scale * i * 1.5, y + scale * 1.5 + 2, x - scale * 3 + scale * i * 1.5 + 0, y + scale * 1.5 + 2);
    }
    gfx.drawLine(x - scale * 3.5 + scale * i * 1.4 + 0, y + scale * 2.5, x - scale * 3 + scale * i * 1.5 + 0, y + scale * 1.5);
    if (scale != Small)
    {
      gfx.drawLine(x - scale * 3.5 + scale * i * 1.4 + 1, y + scale * 2.5, x - scale * 3 + scale * i * 1.5 + 1, y + scale * 1.5);
      gfx.drawLine(x - scale * 3.5 + scale * i * 1.4 + 2, y + scale * 2.5, x - scale * 3 + scale * i * 1.5 + 2, y + scale * 1.5);
    }
  }
}
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
